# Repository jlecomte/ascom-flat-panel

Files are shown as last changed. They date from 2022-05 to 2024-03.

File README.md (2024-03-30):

# ASCOM-Compatible Flat Panel

**IMPORTANT:** This project is no longer actively maintained, and this repository is now a public archive. It has been superseded by [my **wireless** ASCOM-compatible flat panel](https://github.com/jlecomte/ascom-wireless-flat-panel).

I do not charge anything to create and maintain these open-source projects. But if you would like to say "thanks" for this project, feel free to send any amount through Paypal using the button below. I appreciate your support!

(https://www.paypal.com/donate/?hosted_button_id=49UXY8F6VVYFA)

<!-- toc -->

- [Introduction](#introduction)
- [Finished Product](#finished-product)
- [Pre-Requisites](#pre-requisites)
- [Hardware](#hardware)
- [ASCOM Driver](#ascom-driver)
  - [Downloading And Installing The Driver](#downloading-and-installing-the-driver)
  - [Compiling The Driver (For Developers Only)](#compiling-the-driver-for-developers-only)
- [Arduino Firmware](#arduino-firmware)
  - [Microcontroller Compatibility](#microcontroller-compatibility)
  - [Compiling And Uploading The Firmware](#compiling-and-uploading-the-firmware)
- [Mechanical Components](#mechanical-components)
- [Electronic Circuit](#electronic-circuit)
- [Assembling The Flat Panel](#assembling-the-flat-panel)
- [Ideas For Future Enhancements](#ideas-for-future-enhancements)

<!-- tocstop -->

## Introduction

Up until now, I have been using an OSC (One Shot Color) camera (ZWO ASI533MC Pro) to capture images of the night sky with my telescope, along with two filters, a Luminance (L) filter (I use an Astronomik L3 because my budget APO has some residual chromatism in the blue part of the spectrum) and a dual narrowband filter (Optolong L-eXtreme). This makes taking flats relatively easy. I just use an LED tracing panel, which I bought for $20 on Amazon, and I dim the panel using a few sheets of paper in order to accommodate the stark difference in transmission between the two filters (the transmission ratio between these two filters, for a light source that has a relatively broad spectrum, is roughly 1 to 20!)

Recently, in order to get better results, both in terms of SNR and resolution, and to gain more flexibility, specifically with narrowband targets, I have decided to switch to a monochrome camera (I settled on the new and very reasonably priced ZWO ASI533MM Pro). This means that going forward, I will be going from 2 filters to 7 filters (L, R, G, B, H⍺, OIII, SII)! All these filters have wildly varying transmission characteristics, and that makes taking flats a lot more time consuming and difficult.

The solution is relatively straightforward, however. An ASCOM-compatible flat panel is capable of modulating its brightness, and software like N.I.N.A., for example, can control it to adjust its brightness for each filter, while respecting the criteria you set (minimum/maximum exposure time, histogram mean, etc.) The only problem is that commercial flat panels can be quite expensive (depending on their diameter), and unless you are lucky, the flat panel you purchase will likely be bigger than you really need. For instance, for my AT130EDT refractor, the Gerd Neumann flat panel closest in size would be able to fit a 220mm diameter telescope, which is a lot bigger than I need!

What I want is a high quality, affordable (BOM cost ~ $50), yet professional looking ASCOM-compatible flat panel that would be the perfect size for my telescope. The only way to get that was to design it and built it myself, and that is what I did. In this repository, I share everything you need to build your own.

Make sure you check out [this page](https://github.com/jlecomte/circular-led-flat-panel-evaluation) to understand why a Light Guiding Plate (LGP) is absolutely critical for the realization of a high quality flat panel!

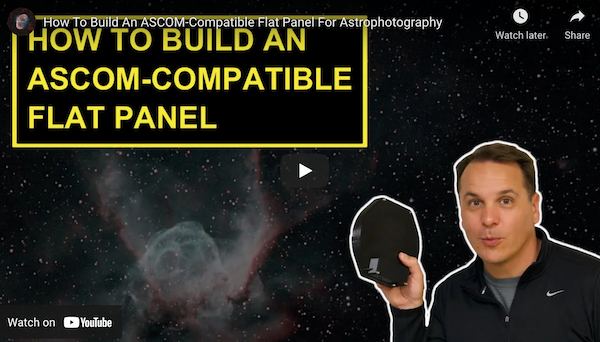
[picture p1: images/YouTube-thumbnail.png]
YouTube video talking about this flat panel (https://www.youtube.com/watch?v=6Nm4YFr4F-w)


## Finished Product

Here is what the finished product looks like:

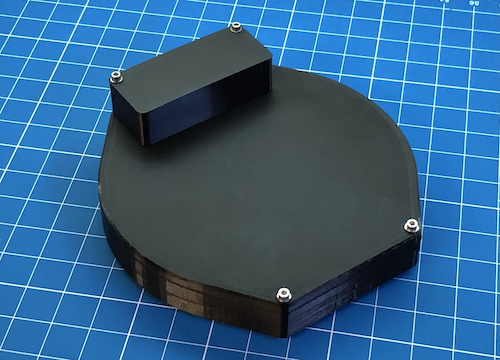
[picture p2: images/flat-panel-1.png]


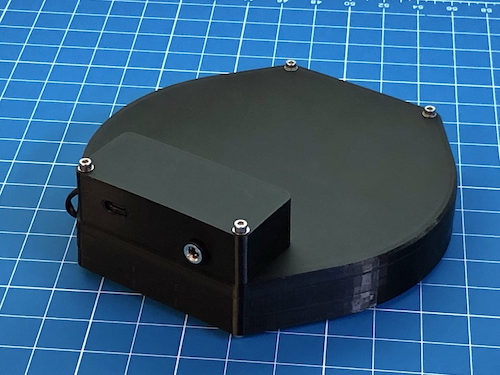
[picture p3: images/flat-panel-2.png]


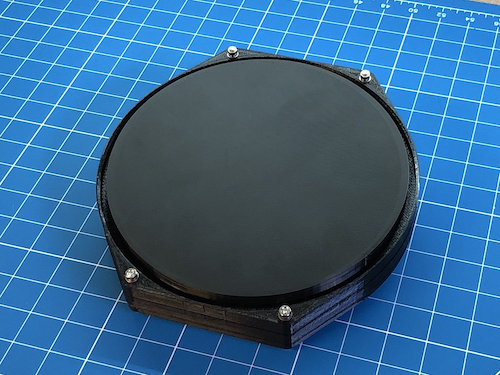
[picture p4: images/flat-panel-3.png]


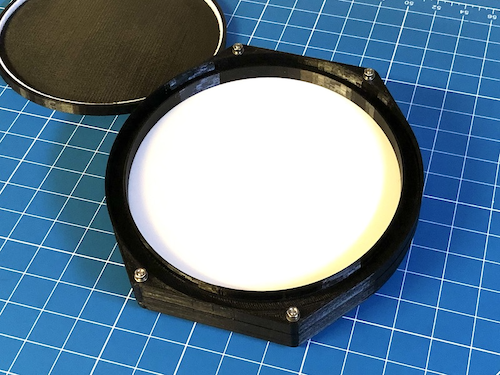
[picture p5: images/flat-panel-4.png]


## Pre-Requisites

* A Windows computer (Windows 10 or newer)
* [Microsoft Visual Studio](https://visualstudio.microsoft.com/) (FYI, I used the 2022 edition...)
* [ASCOM Platform](https://ascom-standards.org/)
* [ASCOM Platform Developer Components](https://ascom-standards.org/COMDeveloper/Index.htm)
* [Arduino IDE](https://www.arduino.cc/en/software)
* [FreeCAD](https://www.freecadweb.org/), a free and open-source 3D parametric modeler
* A 3D printer able to print PETG, and a slicer (I use a heavily upgraded Creality Ender 3 v2, and Ultimaker Cura)
* A few basic tools that any tinkerer must own, such as a breadboard, a soldering iron, etc.

## Hardware

The following are just suggestions... Also, over time, some of the links may no longer work...

* [Seeeduino XIAO](https://www.seeedstudio.com/Seeeduino-XIAO-Arduino-Microcontroller-SAMD21-Cortex-M0+-p-4426.html) (You can get it quicker from Amazon, but you will have to pay twice as much!) See note on microcontroller compatibility below.
* [Natural white LED strip](https://www.amazon.com/dp/B08H4YST71?tag=darkskygeek-20)
* [Mini360 Buck Converter](https://www.amazon.com/dp/B07T7L51ZW?tag=darkskygeek-20)
* IRF520N MOSFET
* 1KΩ resistor
* [Perforated Circuit Board](https://www.amazon.com/dp/B07NM68FXK?tag=darkskygeek-20)
* [DC Power Jack](https://www.amazon.com/dp/B01N8VV78D?tag=darkskygeek-20)
* [Bench Power Supply](https://www.amazon.com/dp/B07GCJ5QHF?tag=darkskygeek-20)
* [Taloya LED Flush Mount Ceiling Light](https://www.amazon.com/dp/B08GX81JB1?tag=darkskygeek-20) (to extract the background disk and the Light Guiding Plate, aka LGP)
* [White Acrylic Sheet](https://www.amazon.com/dp/B083XQ2QS7?tag=darkskygeek-20) (to make the diffuser)
* [Threaded inserts for 3D printed parts](https://www.amazon.com/dp/B07VFZWWXY?tag=darkskygeek-20)
* [Assortment of small metric screws, nuts, and washers](https://www.amazon.com/dp/B08JCKH31Q?tag=darkskygeek-20)
* [22AWG solid core electrical wires](https://www.amazon.com/dp/B088KQFHV7?tag=darkskygeek-20)
* [Easy-to-print PETG filament](https://www.amazon.com/dp/B07PGYHYV8?tag=darkskygeek-20)

**Important note about the LED strip:** Pick a "natural white" LED strip. Stay away from "warm white" because you will run into some problems with your OIII filter (it does not emit enough in the blue part of the spectrum) or "cool white" because you will have similar issues, but with the H⍺ or SII filters (it does not emit enough in the red part of the spectrum). Also, stay away from so-called "high density" LED strips, they are simply too bright for our application. Finally, depending on the exact LED strip you picked and how much voltage you apply (you can set that using the potentiometer on the MINI360 module), you may need to insert additional diffusers. It will be a process of trial and error in order to get the perfect setup. But once you're done, and the Flat Wizard in N.I.N.A. (for example) has been configured for all your filters, taking flats will become a simple "fire and forget" operation.

## ASCOM Driver

### Downloading And Installing The Driver

**Step 1:** Download the driver from the [releases page](https://github.com/jlecomte/ascom-flat-panel/releases), and place the file `ASCOM.DarkSkyGeek.FlatPanel.dll` somewhere on your system (example: `C:\Users\julien\ascom-flat-panel\`).

**Step 2:** Open a command prompt, but make sure you run it **as an administrator**!

**Step 3:** Then, proceed with the installation of the driver using `RegAsm.exe`, a utility that should already be present on your system (it comes with the .NET framework). Just don't forget to use the 64 bit version, and to pass the `/tlb /codebase` flags. Here is what it looked like on my imaging mini computer:

```
> cd C:\Users\julien\ascom-flat-panel\
> C:\Windows\Microsoft.NET\Framework64\v4.0.30319\RegAsm.exe /tlb /codebase ASCOM.DarkSkyGeek.FlatPanel.dll
Microsoft .NET Framework Assembly Registration Utility version 4.8.4161.0
for Microsoft .NET Framework version 4.8.4161.0
Copyright (C) Microsoft Corporation.  All rights reserved.

Types registered successfully
```

**Note:** The output may be more verbose than the above. As long as it says `Types registered successfully`, you are good to go!

**Note:** During registration, you will see a warning that the assembly is unsigned. This is normal as I did not bother going through the pain of signing the assembly, so you will just have to trust that you are registering the DLL that I built and uploaded to GitHub. And if you don't trust me / GitHub, you can build the DLL yourself using Visual Studio.

**Note:** Once the driver has been installed, make sure you do _not_ delete or move the `ASCOM.DarkSkyGeek.FlatPanel.dll` file, or things will not work! (if you do move it, you will need to register it again in its new location)

**Step 4:** Start (or restart, if it was already running) N.I.N.A. (or whatever application you use to control your equipment).

### Compiling The Driver (For Developers Only)

Open Microsoft Visual Studio as an administrator (right click on the Microsoft Visual Studio shortcut, and select "Run as administrator"). This is required because when building the code, by default, Microsoft Visual Studio will register the compiled COM components, and this operation requires special privileges (Note: This is something you can disable in the project settings...) Then, open the solution (`ASCOM_Driver\ASCOM.DarkSkyGeek.FlatPanel.sln`), change the solution configuration to `Release` (in the toolbar), open the `Build` menu, and click on `Build Solution`. As long as you have properly installed all the required dependencies, the build should succeed and the ASCOM driver will be registered on your system. The binary file generated will be `ASCOM_Driver\bin\Release\ASCOM.DarkSkyGeek.FlatPanel.dll`. You may also download this file from the [Releases page](https://github.com/jlecomte/ascom-flat-panel/releases).

## Arduino Firmware

### Microcontroller Compatibility

The firmware was written specifically for, and tested with a Seeeduino Xiao. It will not work on all Arduino-compatible boards. Indeed, if you look at the firmware code, you will notice that I don't use `analogWrite()`. Indeed, the frequency of the PWM wave generated by `analogWrite()` is too low (the exact value depends on the microcontroller — on an Uno, it is 490 Hz, and on a Seeeduino Xiao, it is 790 Hz by default) and any flat taken with an exposure < 1 second showed obvious artifacts (horizontal lines). So I ended up using the Xiao-specific function `pwm()` (might also work on other SAMD boards) to set both the frequency and duty cycle. The frequency I use is 20 kHz, and with that, even flats taken with exposures as low as 0.1 seconds are perfectly usable.

### Compiling And Uploading The Firmware

* Add support for Seeeduino boards by following [the instructions from the board manufacturer](https://wiki.seeedstudio.com/Seeeduino-XIAO/).
* To customize the name of the device when connected to your computer, open the file `boards.txt`, which, on my system and for the version of the Seeeduino board I am using, is located at `%LOCALAPPDATA%\Arduino15\packages\Seeeduino\hardware\samd\1.8.2\boards.txt`. Then, change the value of the key `seeed_XIAO_m0.build.usb_product` from `Seeed XIAO M0` (default) to whatever you'd like. I set it to `DarkSkyGeekʼs ASCOM Flat Panel`.
* Finally, connect your Seeeduino board to your computer (make sure you use a USB-C cable that supports data and not just power!), open the sketch file located at `Arduino_Firmware\Arduino_Firmware.ino`, and click on the `Upload` button in the toolbar.

## Mechanical Components

The STL files you will find in the `3D_Files/STL/` folder are just a starting point. You will likely have to create your own version of this project, if only to match the size of the panel to your own OTA... That is why I included the FreeCAD model in this repository (`3D_Files/Freecad_Model.FCStd`). Since there are no moving parts, it is a relatively simple assembly.

## Electronic Circuit

The electronics circuit is pretty trivial. I included a Fritzing file in the `Electronics/` folder. Here are the schematics:

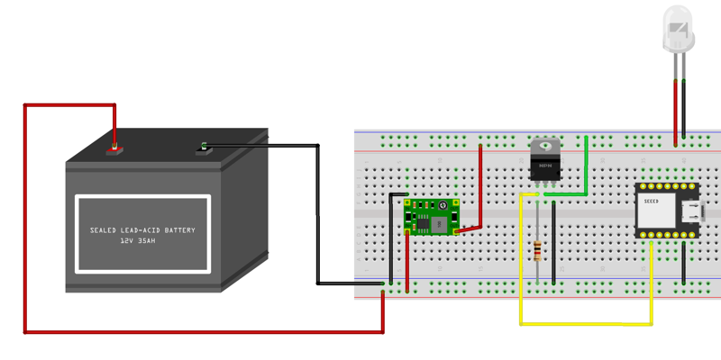
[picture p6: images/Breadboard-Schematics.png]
Circuit Board Box


**IMPORTANT:** When I first tested my circuit, I noticed that the LED strip was flickering. This could not be due to PWM because the microcontroller I am using emits a PWM signal at 490Hz, which is way too fast for your eye to pick it up. For a long time, I thought that there was a bad connection somewhere, but it turned out to be something completely different. The LED strip that I had purchased was rated for 12V. I was under the assumption that I could feed it a slightly higher voltage without any issues (most devices that take in 12V usually work well wihin a range around that median value) but it turned out that the strip's operating range was between 7V and 12V! Since my portable field battery has a voltage of between 12.8V and 13.4V, I had to use a buck converter (in the form of a MINI 360) to bring the voltage down. Actually, tuning the buck converter to output a voltage of about 8.5V (again, highly dependent on the specific LED strip you are using) will lower the brightness, which is a good thing for our application! After that small modification, the flickering is gone and the panel works very well! You can also consider making a simple voltage regulator using a Zener diode and a resistor. There are many ways to manage this kind of situations!

Here is what the finished electronic circuit looks like:

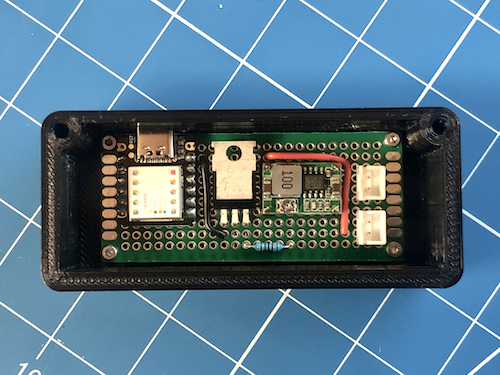
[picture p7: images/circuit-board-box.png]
Electronic Circuit


In the photograph above, the components were soldered onto a 70mm x 30mm PCB.

## Assembling The Flat Panel

The most difficult part of this project is to cleanly and solidly solder wire leads to the appropriate length of LED strip. Once I have a good solder joint, I usually put a nice glob of epoxy resin on and around it to provide some mechanical reinforcement. Then, the LED strip is stuck against the inside of the panel body. The Light Guiding Plate (LGP), cut to size, is inserted and should barely fit within the LED strip, pushing the LEDs against the wall of the panel body. Finally, the spacer is placed on top of the LGP, the diffusing sheet sits on top of the spacer, and the front part of the panel is bolted to the back. Here are a few photos to illustrate this process:

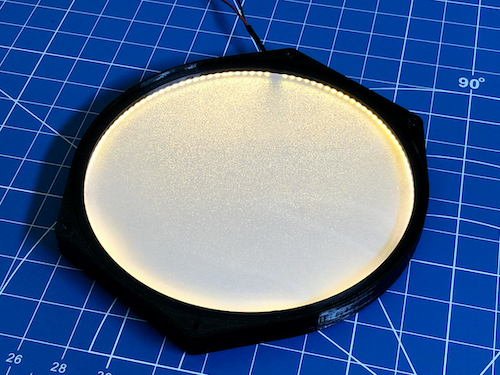
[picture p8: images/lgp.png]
Assembly Process Step 1


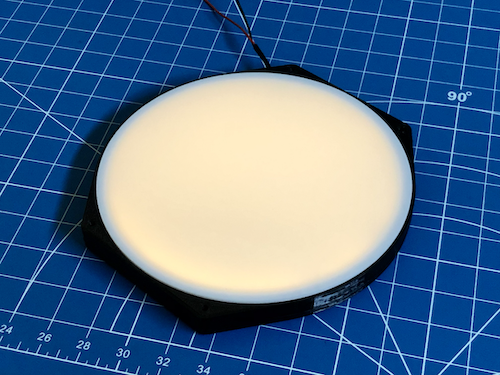
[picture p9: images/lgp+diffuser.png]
Assembly Process Step 2


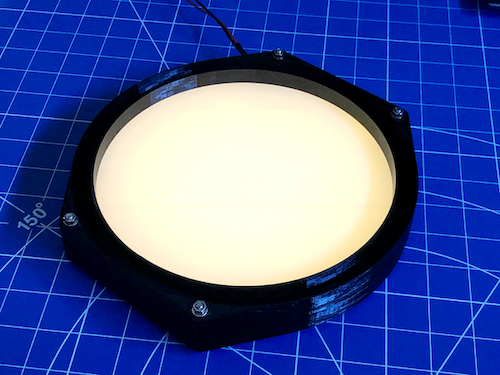
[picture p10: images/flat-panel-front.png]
Assembly Process Step 3


## Ideas For Future Enhancements

* This flat panel could potentially be integrated in the [ASCOM Telescope Cover](https://github.com/jlecomte/ascom-telescope-cover). I decided not to do that because, in my case, it would have added too much weight to the front of my already front-heavy OTA, making it more difficult to balance, and causing all kinds of issues with the camera possibly hitting the tripod legs since the OTA would have to be moved back to provide proper balance.
* It would be nice to power the LED strip from the USB cable, instead of requiring a separate power supply (or maybe use a 9V battery?) Some Arduino-compatible boards boast the ability to deliver as much as 500mA @ 5V, which should be enough to power the LED strip...

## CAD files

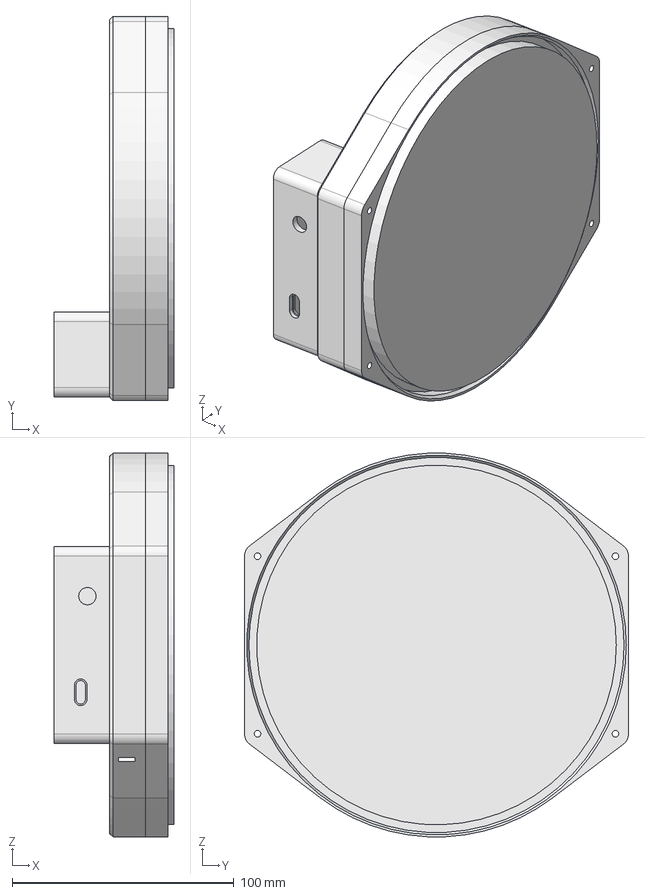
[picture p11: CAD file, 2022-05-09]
3D_Files/Freecad_Model.FCStd
54.0 x 173.0 x 172.8 mm
Flat_Panel_Back
Flat_Panel_Front
Flat_Panel_Spacer
Circuit_Board_Box
Flat_Panel_Lid

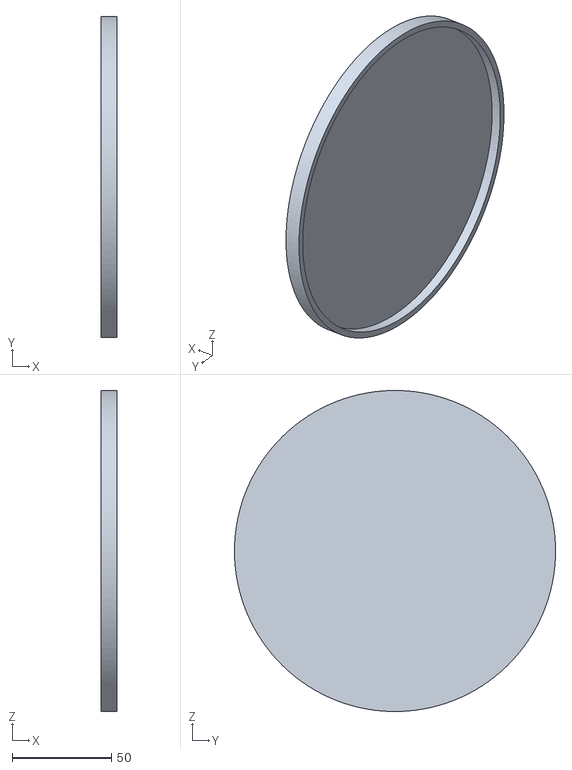
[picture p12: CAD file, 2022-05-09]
3D_Files/STL/Flat_Panel_Lid.stl
8.00 x 162.0 x 161.9

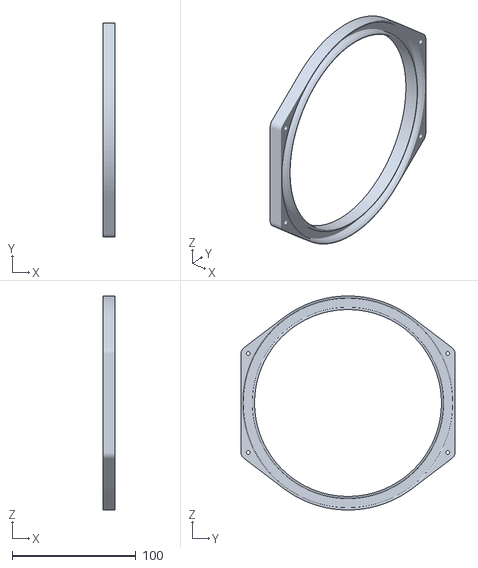
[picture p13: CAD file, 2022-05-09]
3D_Files/STL/Flat_Panel_Front.stl
10.0 x 173.0 x 173.0

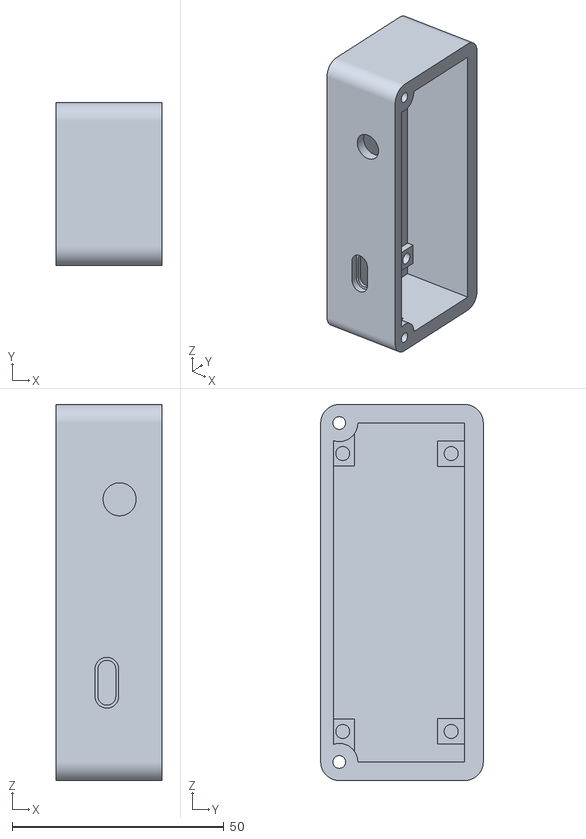
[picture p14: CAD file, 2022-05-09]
3D_Files/STL/Circuit_Board_Box.stl
25.0 x 38.4 x 88.8

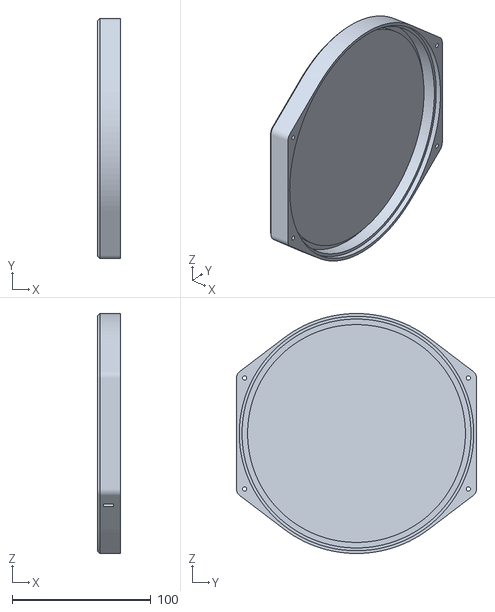
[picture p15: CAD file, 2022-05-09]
3D_Files/STL/Flat_Panel_Back.stl
16.3 x 173.0 x 173.0

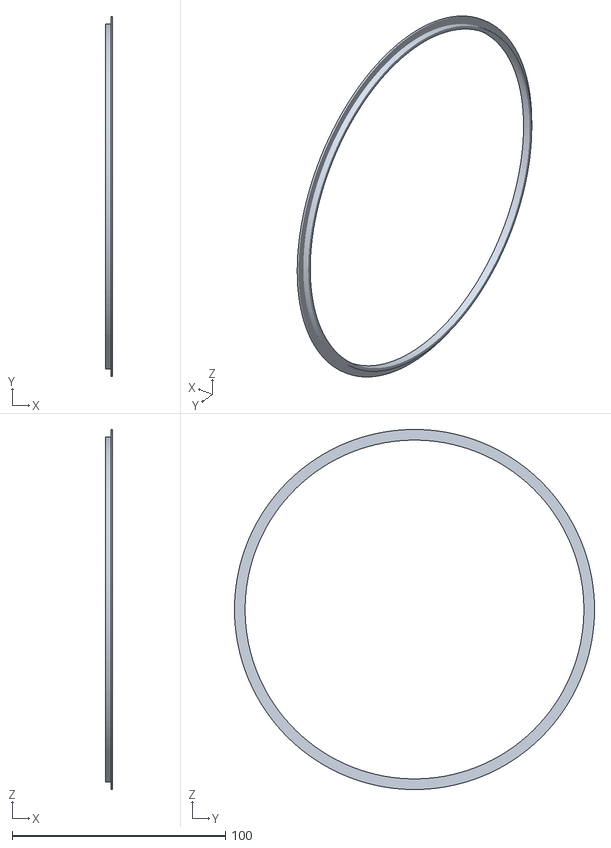
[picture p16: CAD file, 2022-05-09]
3D_Files/STL/Flat_Panel_Spacer.stl
3.50 x 169.0 x 168.9

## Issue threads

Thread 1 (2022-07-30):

CalibratorStatus not ASCOM-Compliant

MiningPickaxe, 2022-07-30:
ASCOM requires the CalibratorStatus to have one of 6 states: https://ascom-standards.org/Help/Developer/html/T_ASCOM_DeviceInterface_CalibratorStatus.htm

You set it to ready all the time, even if it is off. This should at least change between 1 and 3.

I'll try to implement a fix and open a PR tomorrow, should be relatively easy.

jlecomte, 2022-07-30:
Hi! Yes, I remember stumbling upon that while writing the driver. However, considering how the firmware is implemented, I could not see a reason why I would need to use the other states. You say it is not compliant. Is this not working for you when using some ASCOM client application? I have tried it with NINA, and it works fine. That being said, if you open a PR, I will review it. Thank you for the help!

jlecomte, 2022-07-31:
I reviewed the ASCOM page you linked to, and I think that what I do is actually correct. The Ready state can be used even when the panel is turned off as long as it is ready to accept commands. Therefore, I don’t think that this is an issue, and it also does not make the driver non compliant. Feel free to reopen the issue if you think my understanding of the ASCOM API is incorrect. Thank you for the input!

MiningPickaxe, 2022-07-31:
I used ASCOM Conform https://ascom-standards.org/COMDeveloper/Conformance.htm to check the driver, I get this report for the implemented methods:
```
Methods
14:32:38.127 OpenCover                         OK       CoverStatus is 'NotPresent' and a MethodNotImplementedException exception was generated as expected
14:32:38.174 CloseCover                        OK       CoverStatus is 'NotPresent' and a MethodNotImplementedException exception was generated as expected
14:32:38.221 HaltCover                         OK       CoverStatus is 'NotPresent' and a MethodNotImplementedException exception was generated as expected
14:32:38.273 CalibratorOn                      OK       CalibratorOn with brightness -1 threw an InvalidValueException as expected
14:32:38.314 CalibratorOn                      OK       CalibratorOn with brightness 0 was successful. The synchronous operation took 0,0 seconds
14:32:38.322 CalibratorOn                      OK       The Brightness property does return the value that was set
14:32:38.362 CalibratorOn                      OK       CalibratorOn with brightness 1 was successful. The synchronous operation took 0,0 seconds
14:32:38.368 CalibratorOn                      OK       The Brightness property does return the value that was set
14:32:38.408 CalibratorOn                      OK       CalibratorOn with brightness 2 threw an InvalidValueException as expected
14:32:38.454 CalibratorOff                     ERROR    CalibratorOff was unsuccessful - the returned CalibratorState was 'Ready' instead of 'Off'. The synchronous action took 0,0 seconds
```

N.I.N.A. does indeed not care about this and works just fine.

If you turn off the calibrator the brightness should indeed be 0, but how I understand the Conform output and documentation about the CalibratorStatus, a call to CalibratorOff() should set the CalibratorStatus to 1.

The Calibrator is "Ready" when the light is on and brightess > 0 and it is "Ready" to be used and it is "Off" if the light is off and the brightness == 0.

With my fix applied the output looks like this:
```
Methods
14:39:02.618 OpenCover                         OK       CoverStatus is 'NotPresent' and a MethodNotImplementedException exception was generated as expected
14:39:02.669 CloseCover                        OK       CoverStatus is 'NotPresent' and a MethodNotImplementedException exception was generated as expected
14:39:02.716 HaltCover                         OK       CoverStatus is 'NotPresent' and a MethodNotImplementedException exception was generated as expected
14:39:02.766 CalibratorOn                      OK       CalibratorOn with brightness -1 threw an InvalidValueException as expected
14:39:02.810 CalibratorOn                      OK       CalibratorOn with brightness 0 was successful. The synchronous operation took 0,0 seconds
14:39:02.817 CalibratorOn                      OK       The Brightness property does return the value that was set
14:39:02.858 CalibratorOn                      OK       CalibratorOn with brightness 1 was successful. The synchronous operation took 0,0 seconds
14:39:02.864 CalibratorOn                      OK       The Brightness property does return the value that was set
14:39:02.901 CalibratorOn                      OK       CalibratorOn with brightness 2 threw an InvalidValueException as expected
14:39:02.950 CalibratorOff                     OK       CalibratorOff was successful. The synchronous action took 0,0 seconds
14:39:02.957 CalibratorOff                     OK       Brightness is set to zero when the calibrator is turned off
```

jlecomte, 2022-07-31:
OK, interesting. Maybe the ASCOM API docs should be updated? Thank you for opening a PR, I will review it in a couple of weeks, as soon as I’m back from my vacation :)

MiningPickaxe, 2022-07-31:
Sure, enjoy your vaca!

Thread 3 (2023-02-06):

LED in frizting schematic appears to be reversed

fmeschia, 2023-02-06:
The LED that represent the LED strip in the Fritzing schematic appears to be reverse-biased. If connected that way, no light would come out.

jlecomte, 2023-02-07:
Indeed! Thank you for catching this. Fix is on the way :)

jlecomte, 2023-02-07:
Fixed in https://github.com/jlecomte/ascom-flat-panel/commit/3967d9b0d804235080aa38a7e6543275936aa352

Closed 2023-02-07.

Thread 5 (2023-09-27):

Adjusting Global Settings in Free CAD

HeavyJohnny, 2023-09-27:
Thank you so much for making this project public. I purchased everything to build this project and I sat down to print out the housing using the free cad file you provided. However, when resizing the unit to fit my esprit 120 using the global settings (OTA Outside diameter 175mm, and OTA thickness 7mm) I get an error on Pad009 Sketch018.  Recompute Failed. I am not a Free CAD user I use OnShape for all my projects so I have no clue how to correct it or even how to drill down to look at the error. Is there another parameter I need to change in Globals? Thanks again

jlecomte, 2023-09-27:
If you can wait a few more months, I’ll have an entirely new version that will resolve this issue and bring several improvements. To find out when it’s available, subscribe to my YouTube channel. I’ll probably make a detailed video about it.

HeavyJohnny, 2023-09-27:
I have been subscribed to you channel for a while now, I enjoy it, and I cant wait to see the improvements! In the next video I would love to see you build it too. It would be awesome to follow along with you. Thanks again. Also, I was able to print it despite the errors. It turned out great too.

jlecomte, 2023-09-27:
Yes, absolutely, for the new and improved version, I will show how it is assembled and how I cleanly cut the diffuser and the LGP. Hopefully, this will happen before the end of this year, if all goes well. Thanks!

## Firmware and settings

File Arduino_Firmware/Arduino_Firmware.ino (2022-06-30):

/*
 * Arduino_Firmware.ino
 * Copyright (C) 2022 - Present, Julien Lecomte - All Rights Reserved
 * Licensed under the MIT License. See the accompanying LICENSE file for terms.
 */

constexpr auto DEVICE_GUID = "7e2006ab-88b5-4b09-b0b3-1ac3ca8da43e";

constexpr auto COMMAND_PING = "COMMAND:PING";
constexpr auto RESULT_PING = "RESULT:PING:OK:";

constexpr auto COMMAND_INFO = "COMMAND:INFO";
constexpr auto RESULT_INFO = "RESULT:INFO:DarkSkyGeek's Flat Panel Firmware v1.0";

constexpr auto COMMAND_CALIBRATOR_GETBRIGHTNESS = "COMMAND:CALIBRATOR:GETBRIGHTNESS";
constexpr auto COMMAND_CALIBRATOR_ON = "COMMAND:CALIBRATOR:ON:";
constexpr auto COMMAND_CALIBRATOR_OFF = "COMMAND:CALIBRATOR:OFF";
constexpr auto RESULT_CALIBRATOR_BRIGHTNESS = "RESULT:CALIBRATOR:BRIGHTNESS:";

constexpr auto ERROR_INVALID_COMMAND = "ERROR:INVALID_COMMAND";

#define MIN_BRIGHTNESS 0
#define MAX_BRIGHTNESS 255
#define PWM_FREQ 20000

byte brightness = 0;

int ledPin = 8;

// The `setup` function runs once when you press reset or power the board.
void setup() {
    // Initialize serial port I/O.
    Serial.begin(57600);
    while (!Serial) {
        ; // Wait for serial port to connect. Required for native USB!
    }
    Serial.flush();

    // Make sure the RX, TX, and built-in LEDs don't turn on, they are very bright!
    // Even though the board is inside an enclosure, the light can be seen shining
    // through the small opening for the USB connector! Unfortunately, it is not
    // possible to turn off the power LED (green) in code...
    pinMode(PIN_LED_TXL, INPUT);
    pinMode(PIN_LED_RXL, INPUT);
    pinMode(LED_BUILTIN, OUTPUT);
    digitalWrite(LED_BUILTIN, HIGH);

    // Setup LED pin as output
    pinMode(ledPin, OUTPUT);
}

// The `loop` function runs over and over again until power down or reset.
void loop() {
    if (Serial.available() > 0) {
        String command = Serial.readStringUntil('\n');
        if (command == COMMAND_PING) {
            handlePing();
        }
        else if (command == COMMAND_INFO) {
            sendFirmwareInfo();
        }
        else if (command == COMMAND_CALIBRATOR_GETBRIGHTNESS) {
            sendCalibratorBrightness();
        }
        else if (command.startsWith(COMMAND_CALIBRATOR_ON)) {
            String arg = command.substring(strlen(COMMAND_CALIBRATOR_ON));
            byte value = (byte) arg.toInt();
            calibratorOn(value);
        }
        else if (command == COMMAND_CALIBRATOR_OFF) {
            calibratorOff();
        }
        else {
            handleInvalidCommand();
        }
    }
}

//-- CALIBRATOR HANDLING ------------------------------------------------------

void sendCalibratorBrightness() {
    Serial.print(RESULT_CALIBRATOR_BRIGHTNESS);
    Serial.println(brightness);
}

void setBrightness() {
    // This only works on Seeeduino Xiao.
    // The `pwm` function is defined in the following file:
    // %localappdata%\Arduino15\packages\Seeeduino\hardware\samd\1.8.2\cores\arduino\wiring_pwm.cpp
    // For other Arduino-compatible boards, consider using:
    //   analogWrite(ledPin, brightness);
    // The nice thing about the `pwm` function is that we can set the frequency
    // to a much higher value (I use 20kHz) This does not work on all pins!
    // For example, it does not work on pin 7 of the Xiao, but it works on pin 8.
    int value = map(brightness, MIN_BRIGHTNESS, MAX_BRIGHTNESS, 0, 1023);
    pwm(ledPin, PWM_FREQ, value);
}

void calibratorOn(byte _brightness) {
    brightness = _brightness;
    setBrightness();
}

void calibratorOff() {
    brightness = 0;
    setBrightness();
}

//-- MISCELLANEOUS ------------------------------------------------------------

void handlePing() {
    Serial.print(RESULT_PING);
    Serial.println(DEVICE_GUID);
}

void sendFirmwareInfo() {
    Serial.println(RESULT_INFO);
}

void handleInvalidCommand() {
    Serial.println(ERROR_INVALID_COMMAND);
}

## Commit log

2022-05-09 Added 3D files
    [Circuit_Board_Box.stl, Flat_Panel_Back.stl, Flat_Panel_Front.stl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]
2022-05-09 Added electronics circuit and images
    [Breadboard_Circuit.fzz]
2022-05-09 Added flat panel lid
    [Flat_Panel_Lid.stl, Freecad_Model.FCStd]
2022-05-16 Added note about LED strip voltage rating
2022-05-31 Use PWM high frequency and turn off panel upon disconnection
2022-06-02 Updated electronics schematics
    [Breadboard_Circuit.fzz]
2022-06-30 Turn off all LEDs on Xiao board
2022-09-18 Fixed incorrect wiring in electronics schematics
    [Breadboard_Circuit.fzz]
2022-11-30 Removed driver template file
2023-02-07 Fixed polarity of LED in Fritzing schematics [issue #3]
    [Breadboard_Circuit.fzz]
